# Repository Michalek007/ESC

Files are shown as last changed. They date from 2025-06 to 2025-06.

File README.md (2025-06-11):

# ESC
Electronic speed control for BLDC motors with 6STEP algorithm.

## Hardware
Schematics and PCB project. ESC was based on STSPIN32F0A microcontroller and PSMNR55-40SSH MOSFETs.

## Firmware
Code for STSPIN32F0A in C. Implementation of a 6-step algorithm for controlling motor speed using the Motor SDK. Controlling motor speed with PWM and DShot protocol. UART interface for motor's telemetry.

## ESC Pilot
Python application that communicates with the ESC via UART, enabling motor testing, telemetry collection, and motor speed control.

## Images
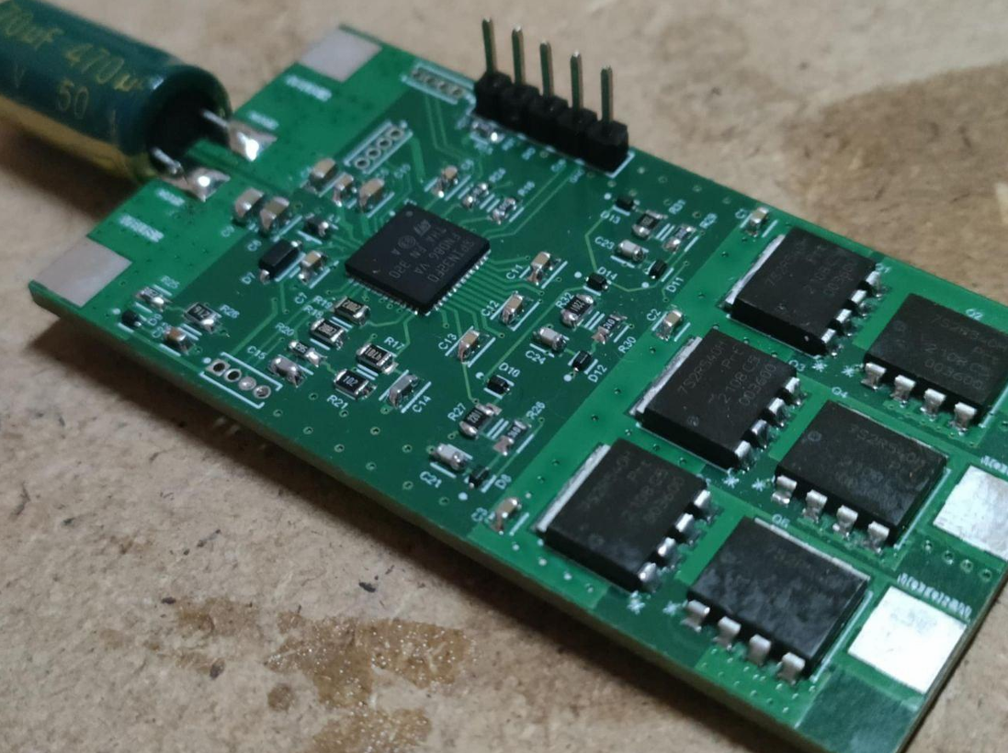
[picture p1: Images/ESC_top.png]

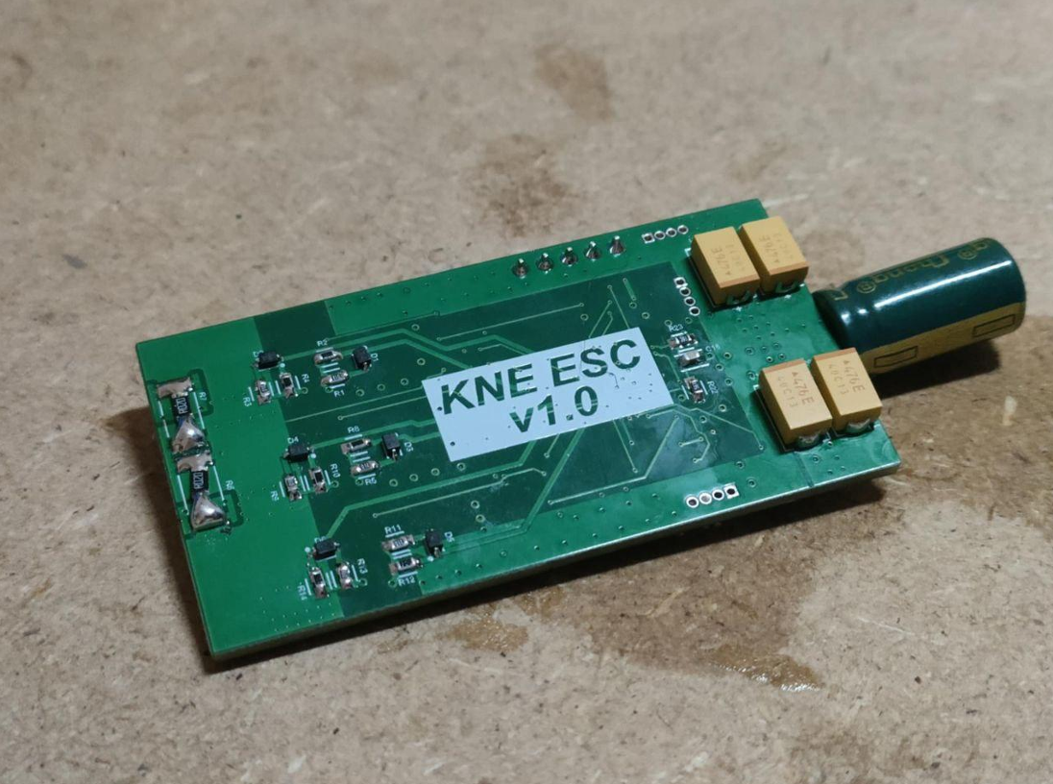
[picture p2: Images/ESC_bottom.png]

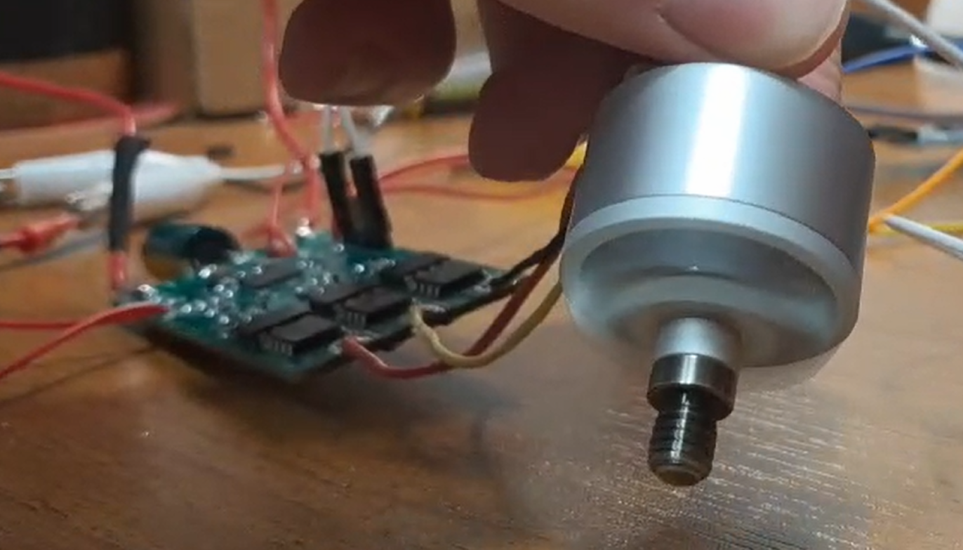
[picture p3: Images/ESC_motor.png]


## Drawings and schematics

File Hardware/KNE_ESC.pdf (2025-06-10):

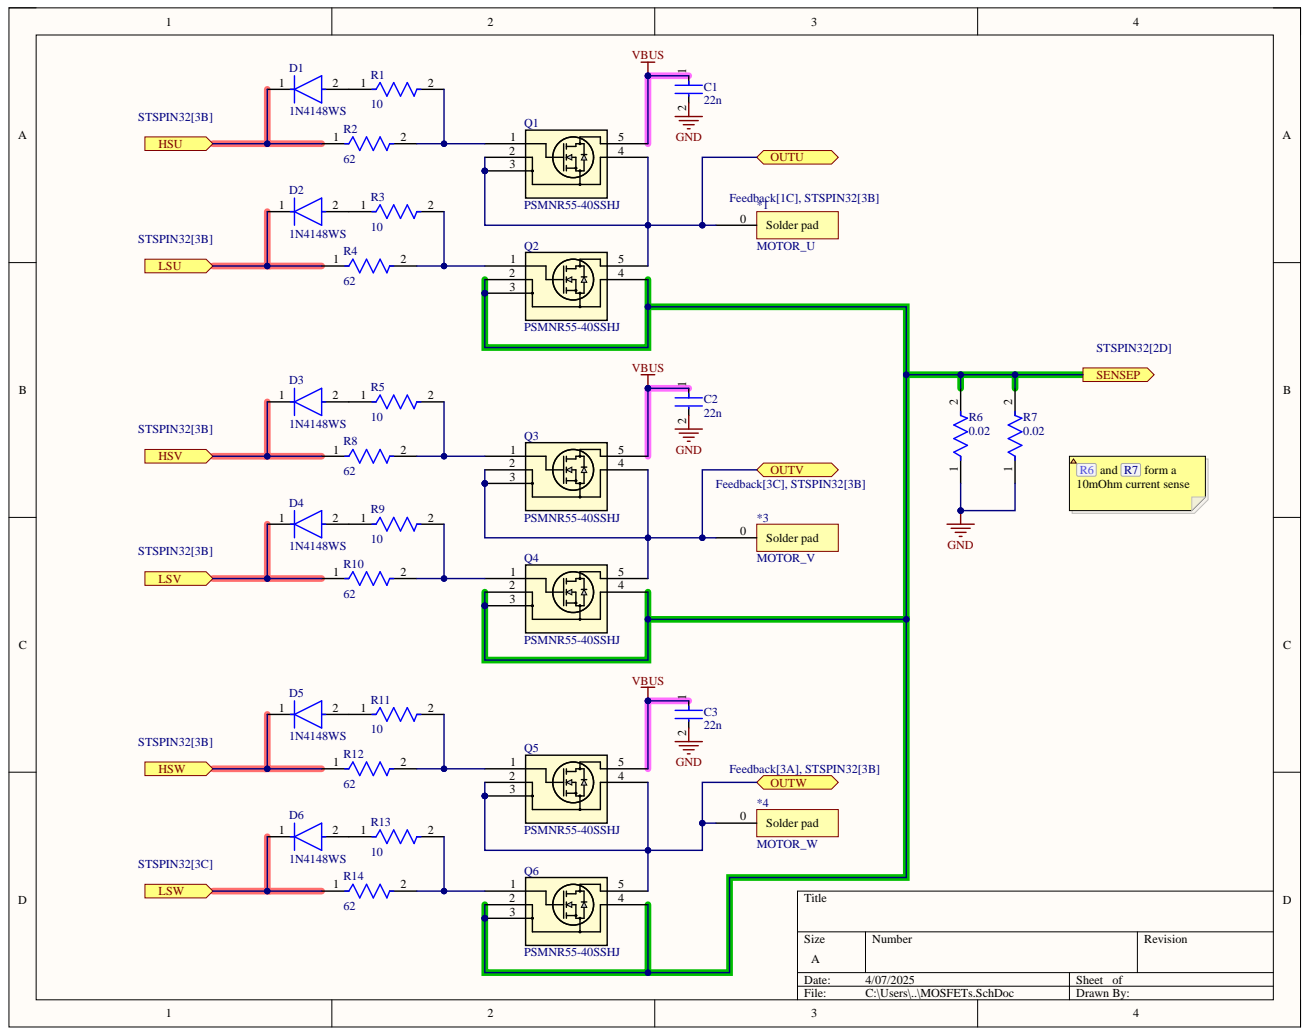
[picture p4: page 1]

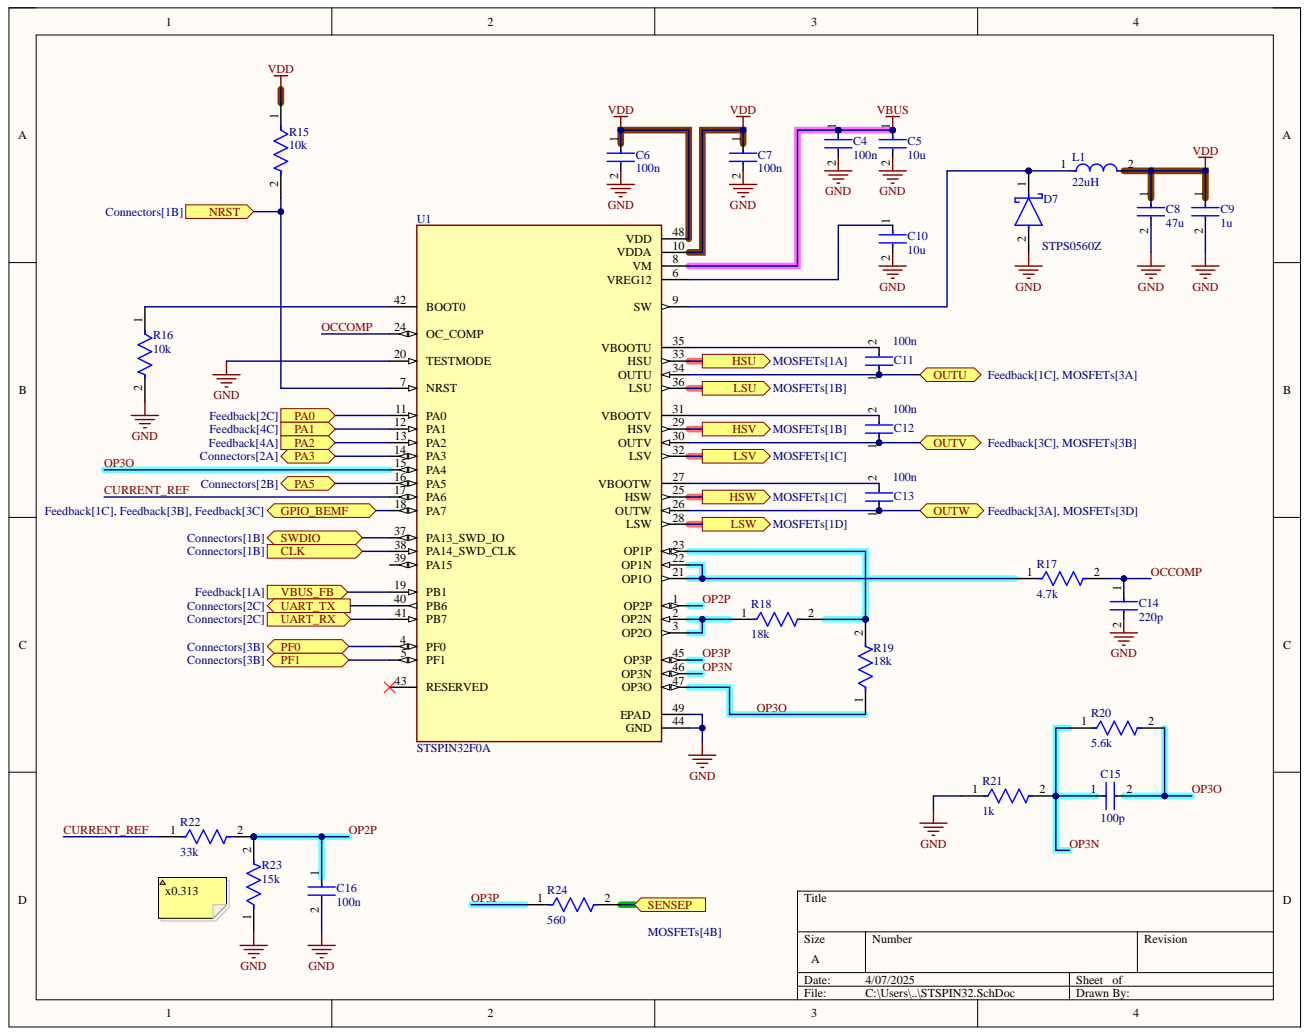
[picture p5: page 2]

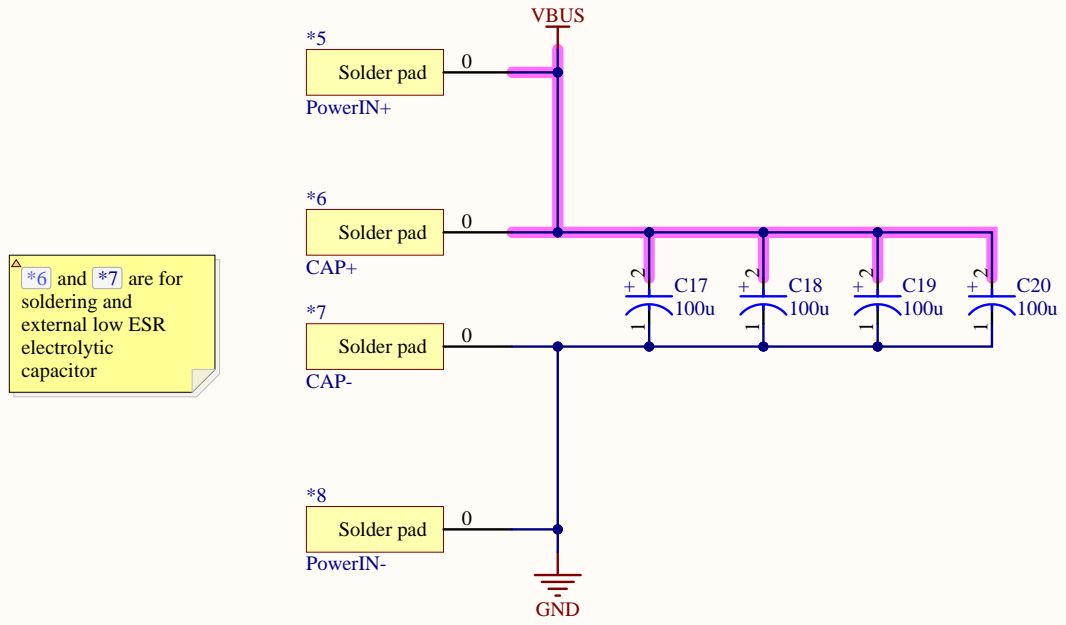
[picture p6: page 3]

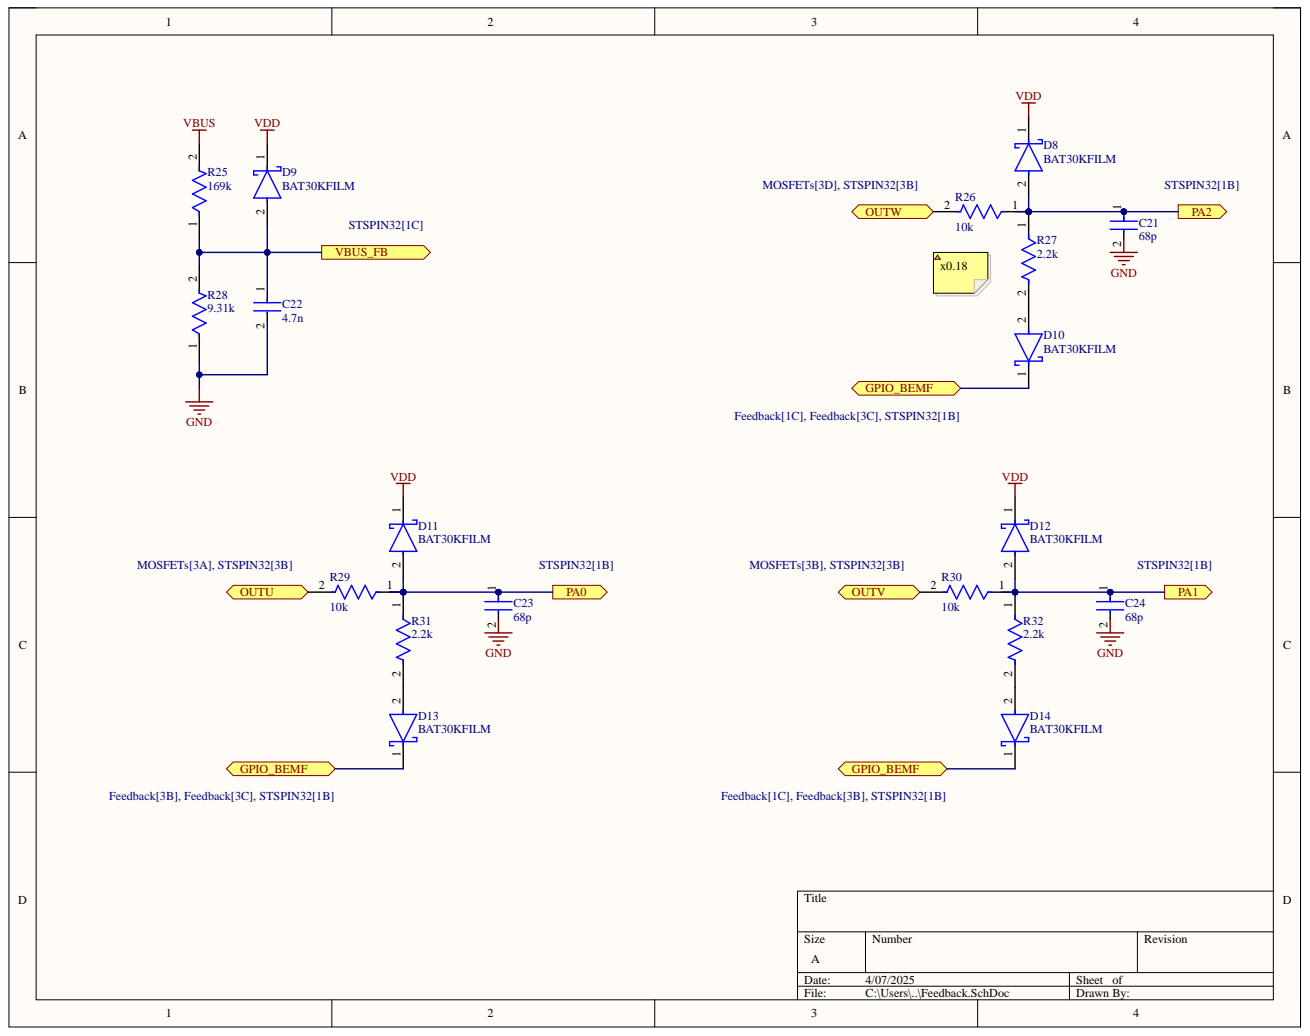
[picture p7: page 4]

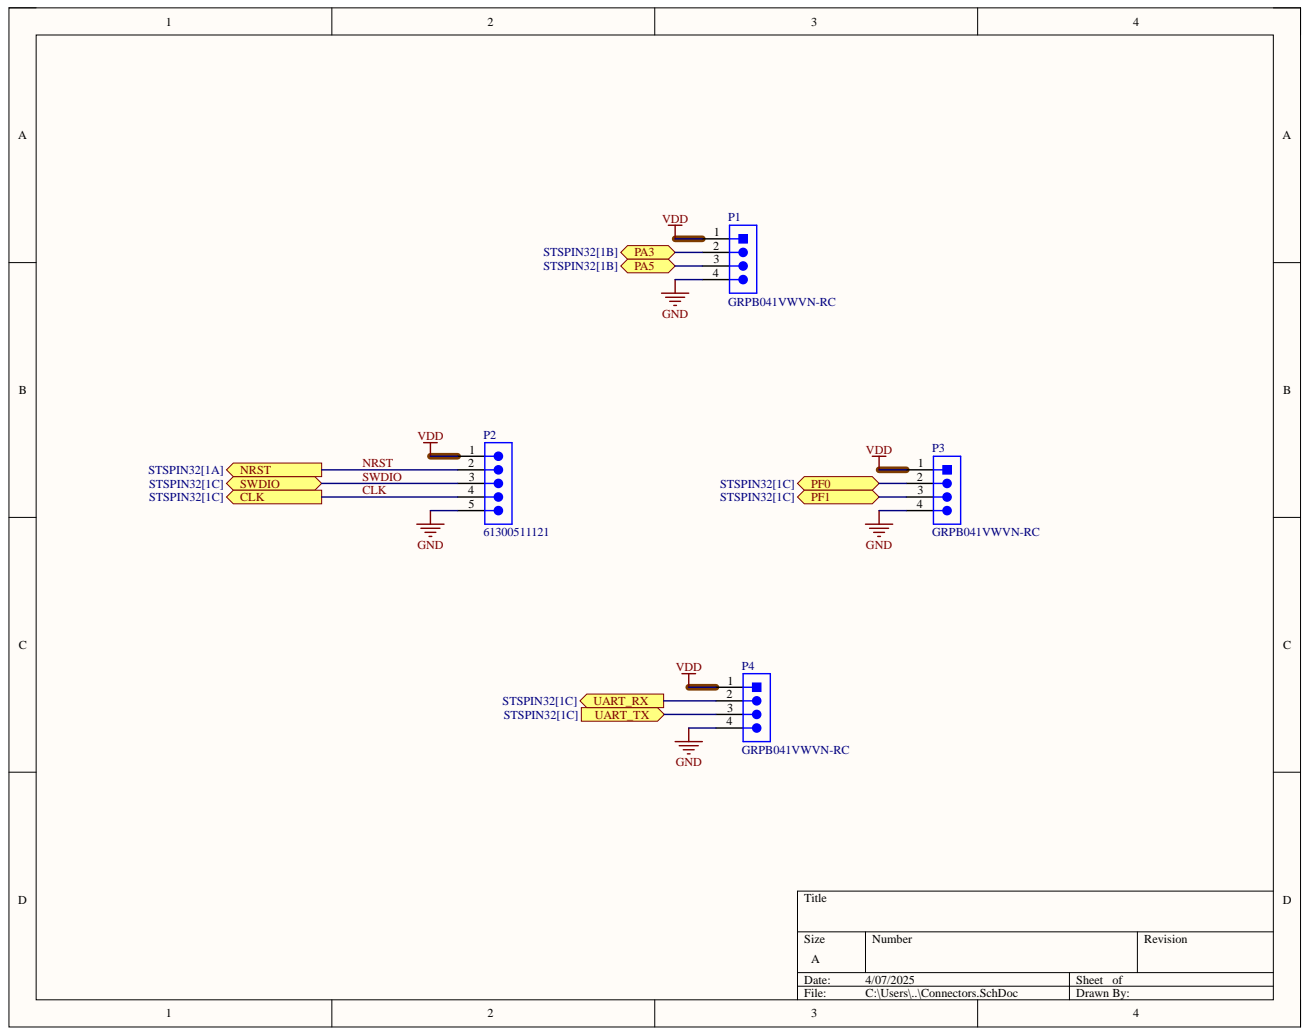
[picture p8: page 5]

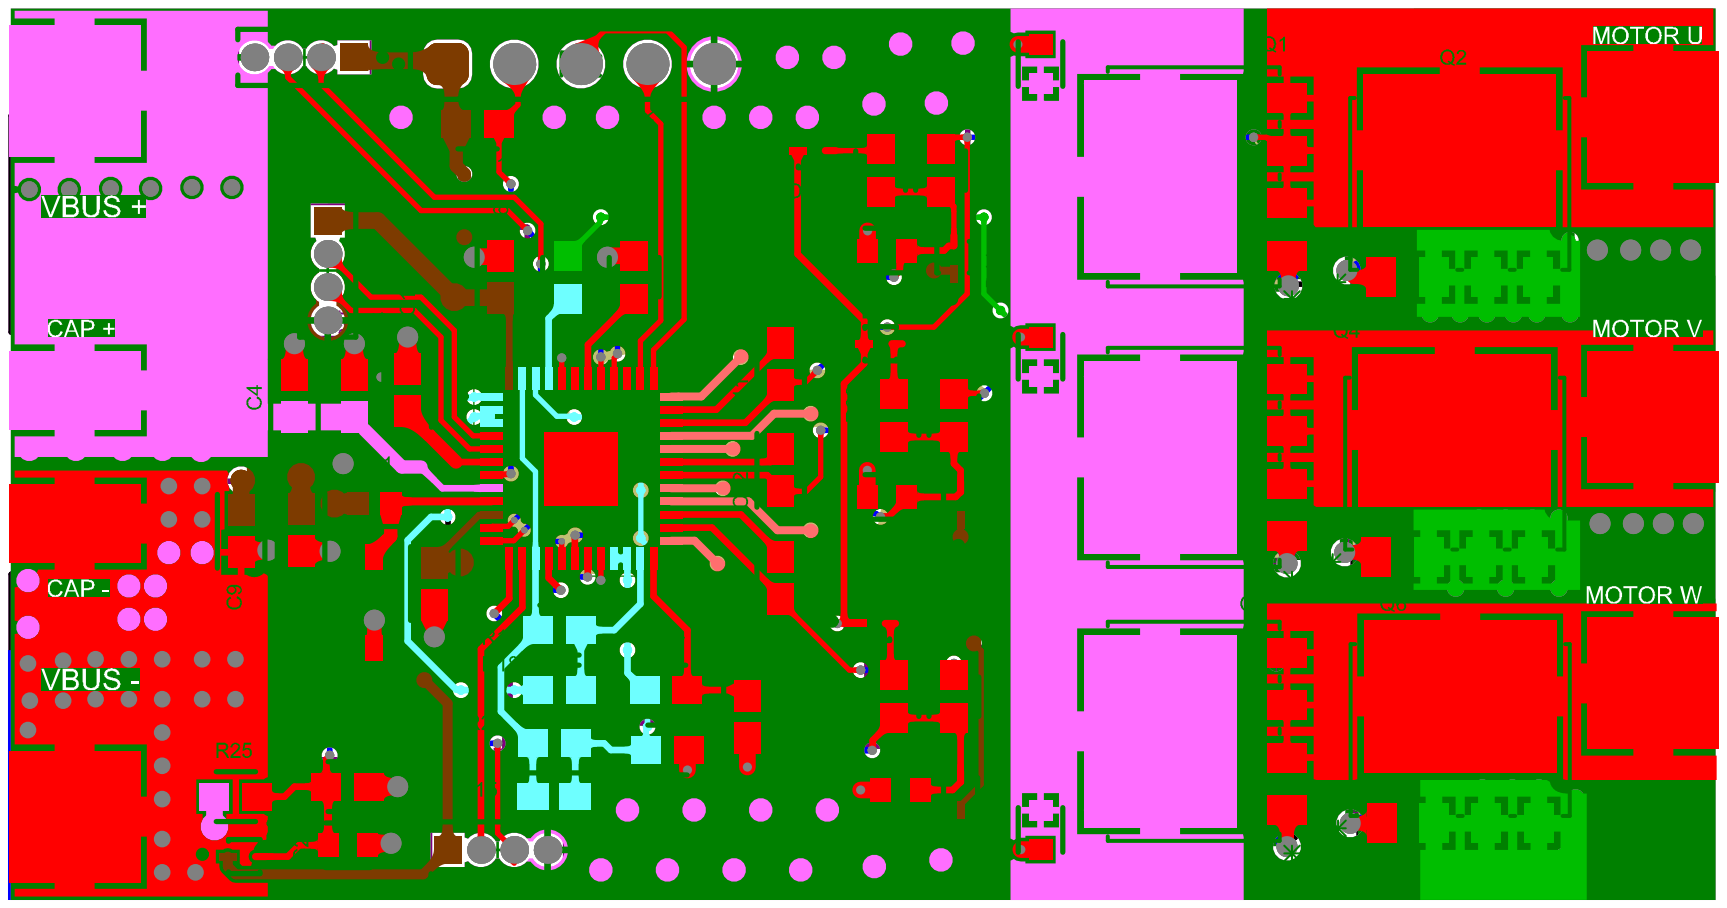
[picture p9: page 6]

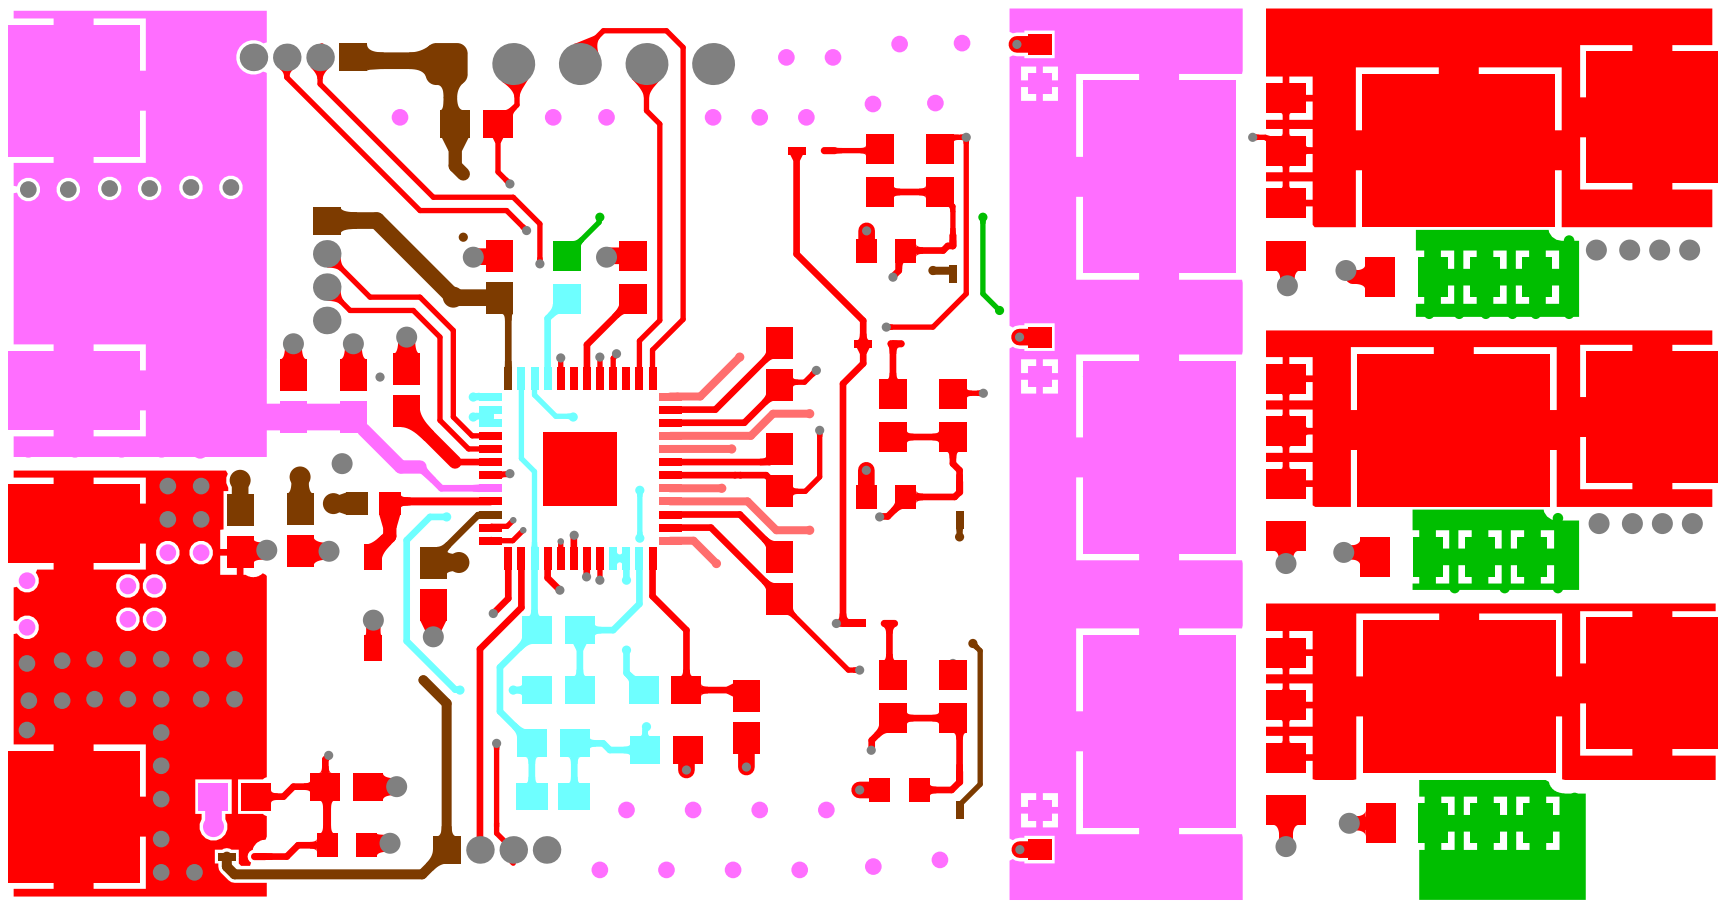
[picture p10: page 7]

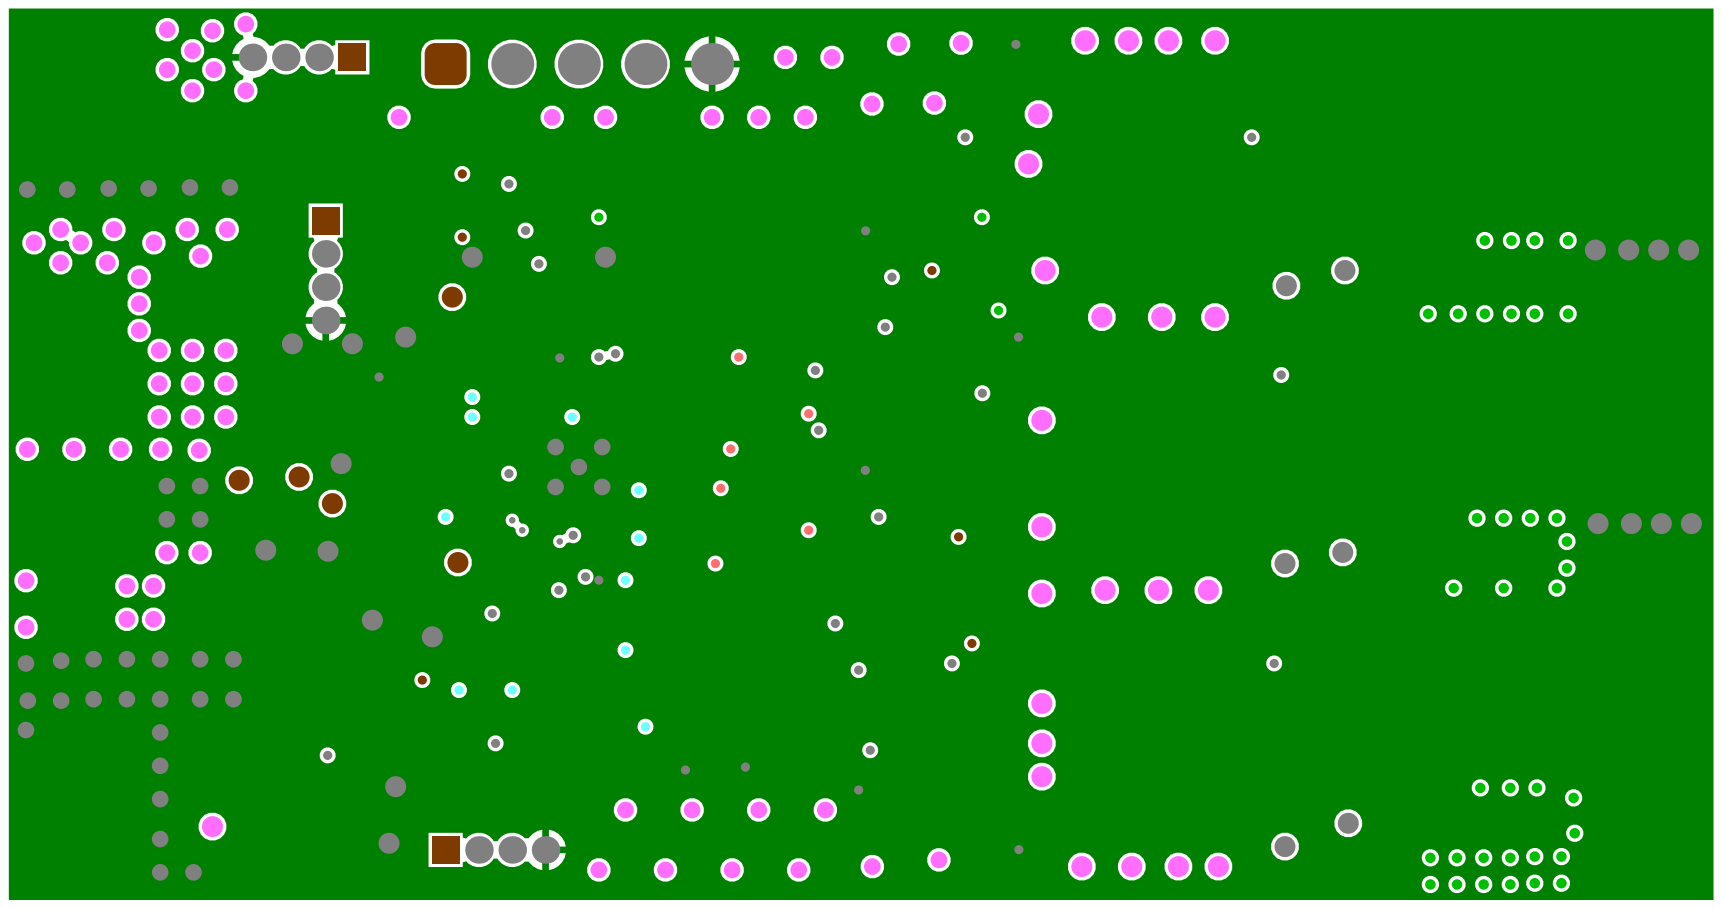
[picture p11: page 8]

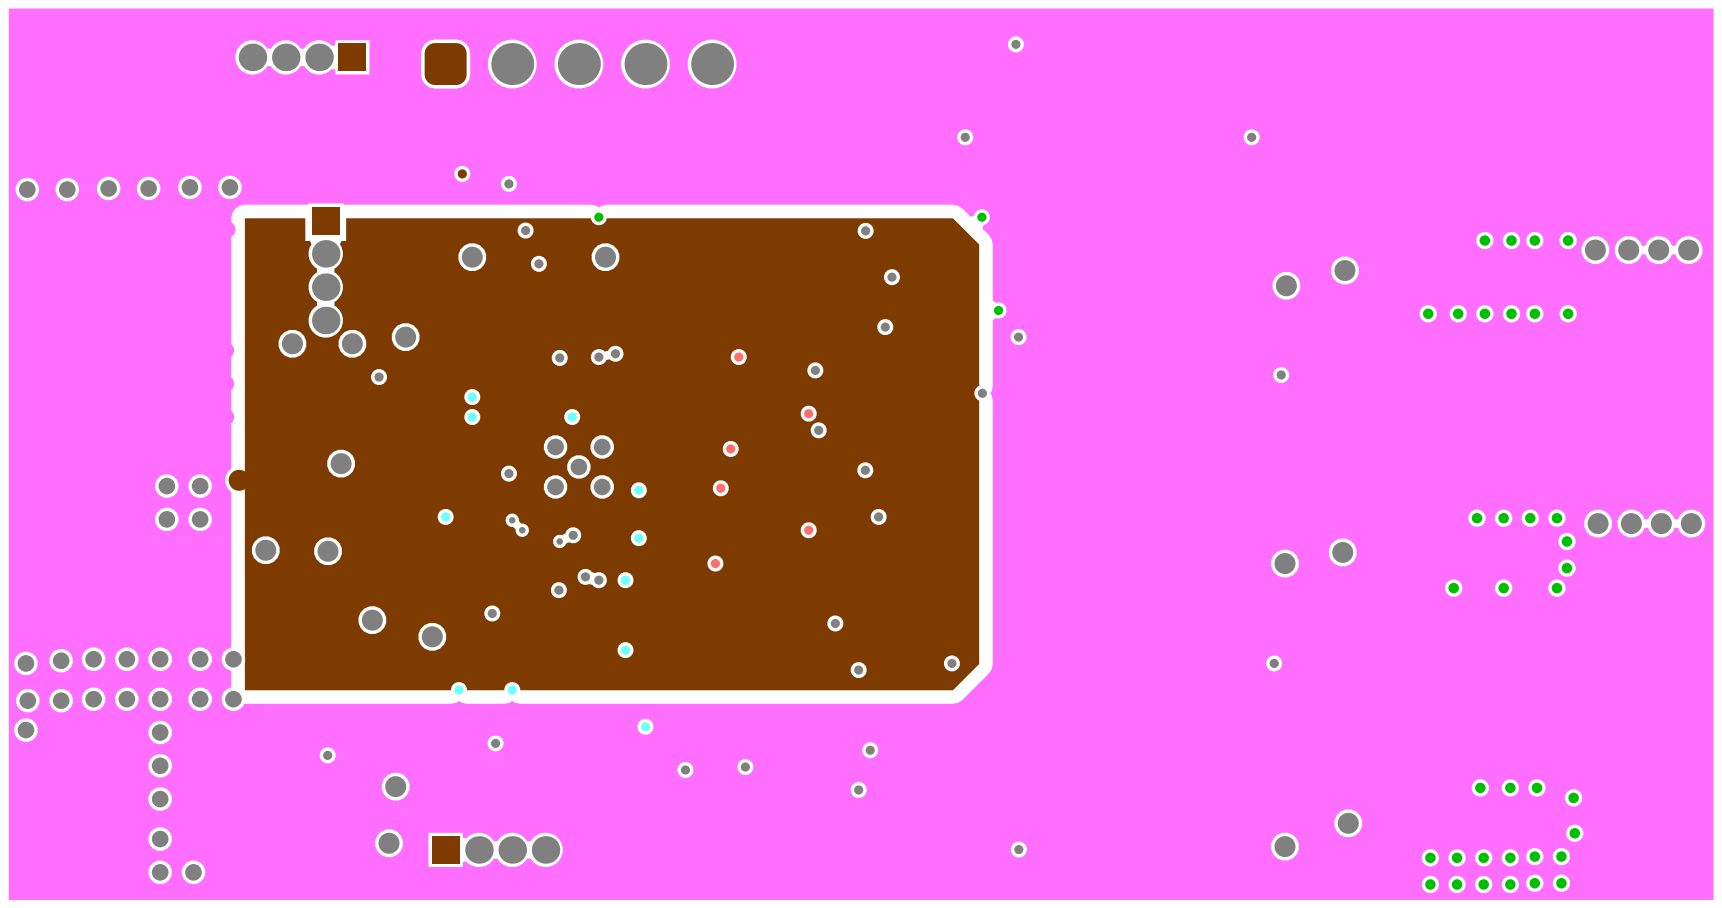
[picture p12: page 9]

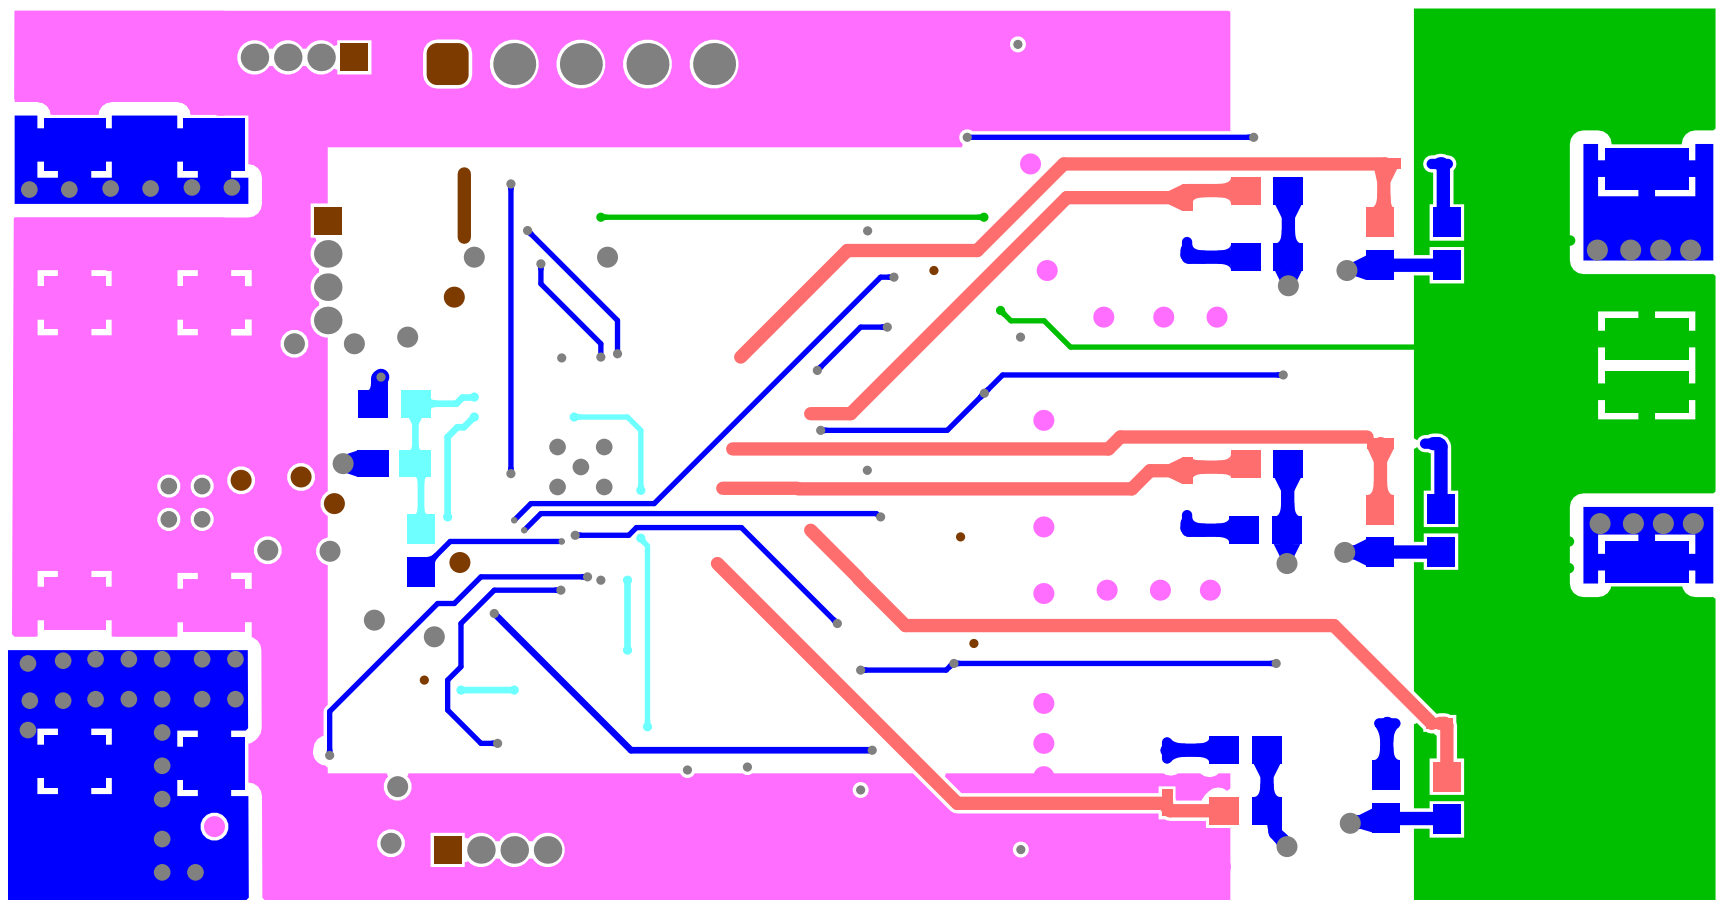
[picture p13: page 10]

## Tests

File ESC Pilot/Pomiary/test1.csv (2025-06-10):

Time | Time | Time | DutyCycle | ReferenceSpeed | AverageSpeed | MotorState
1749584591.8437037 | 2025-06-10 19:43:11.844 | 0.000 | 233 | 4500 | 492 | START
1749584592.9468708 | 2025-06-10 19:43:12.947 | 1.103 | 121 | 3996 | 1494 | RUN
1749584594.0984666 | 2025-06-10 19:43:14.098 | 2.255 | 115 | 3996 | 3468 | RUN
1749584595.1688685 | 2025-06-10 19:43:15.169 | 3.325 | 109 | 3996 | 3720 | RUN
1749584596.2884579 | 2025-06-10 19:43:16.288 | 4.445 | 104 | 4998 | 4698 | RUN
1749584597.3765178 | 2025-06-10 19:43:17.377 | 5.533 | 106 | 4998 | 4938 | RUN
1749584598.4796581 | 2025-06-10 19:43:18.480 | 6.636 | 107 | 4998 | 4980 | RUN
1749584599.599031 | 2025-06-10 19:43:19.599 | 7.755 | 105 | 4998 | 4896 | RUN
1749584600.718403 | 2025-06-10 19:43:20.718 | 8.875 | 109 | 4998 | 5076 | RUN
1749584601.9016843 | 2025-06-10 19:43:21.902 | 10.058 | 102 | 6000 | 5874 | RUN
1749584603.036604 | 2025-06-10 19:43:23.037 | 11.193 | 99 | 6000 | 5796 | RUN
1749584604.1402366 | 2025-06-10 19:43:24.140 | 12.297 | 98 | 6000 | 5748 | RUN
1749584605.3079164 | 2025-06-10 19:43:25.308 | 13.464 | 104 | 6000 | 6006 | RUN
1749584606.4584975 | 2025-06-10 19:43:26.458 | 14.615 | 103 | 6996 | 7056 | RUN
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

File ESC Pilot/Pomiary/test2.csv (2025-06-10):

Time | DutyCycle | ReferenceSpeed | AverageSpeed | MotorState
1749585109.303835 | 801 | 4500 | 0 | IDLE
1749585111.6242926 | 801 | 4500 | 0 | IDLE
1749585113.3018076 | 801 | 4500 | 0 | IDLE
1749585114.9172814 | 801 | 4500 | 0 | IDLE
1749585116.0360553 | 801 | 4500 | 0 | IDLE
1749585117.253012 | 801 | 4500 | 0 | IDLE
1749585118.7549648 | 801 | 4500 | 0 | IDLE
1749585120.2897549 | 801 | 4500 | 0 | IDLE
1749585121.5050356 | 801 | 4500 | 0 | IDLE
1749585122.7847323 | 233 | 4500 | 150 | START
1749585124.4796014 | 114 | 3996 | 1932 | RUN
1749585125.9988434 | 112 | 3996 | 3648 | RUN
1749585127.981447 | 110 | 4998 | 5058 | RUN
1749585129.6124997 | 106 | 4998 | 4938 | RUN
1749585131.2120302 | 109 | 4998 | 5130 | RUN
1749585132.6668863 | 104 | 6000 | 5994 | RUN
1749585134.2183836 | 103 | 6000 | 5994 | RUN
1749585135.769585 | 99 | 6000 | 5808 | RUN
1749585137.2725961 | 99 | 6996 | 6834 | RUN
1749585138.7280366 | 102 | 6996 | 7062 | RUN
1749585140.230938 | 99 | 6996 | 6990 | RUN
1749585141.6537375 | 98 | 6996 | 6894 | RUN
1749585143.0447867 | 90 | 7998 | 7794 | RUN
1749585144.4378734 | 93 | 7998 | 8076 | RUN
1749585145.8917708 | 86 | 7998 | 7980 | RUN
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

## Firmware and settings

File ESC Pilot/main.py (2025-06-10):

import tkinter as tk
from tkinter import ttk
import threading
import time
import struct
import csv
import random
import matplotlib.pyplot as plt
from matplotlib.backends.backend_tkagg import FigureCanvasTkAgg
from mc_api import *


class EscConnectivity:
    def __init__(self):
        self.current_speed = 0
        self.uart = UART()

    def set_speed(self, speed_rpm: int):
        self.uart.send_mc_packet(McPacket.set_speed_rpm(speed_rpm))
        self.current_speed = speed_rpm

    def read_telemetry(self):
        mc_packet = self.uart.send_mc_packet(McPacket.telemetry_request())
        print(mc_packet)
        if not mc_packet:
            return 0, 0, 0, 0, 0
        return mc_packet.duty_cycle, mc_packet.reference_speed, mc_packet.average_speed, mc_packet.motor_state, mc_packet.crc


class MotorGUI:
    def __init__(self, root):
        self.master = root
        self.comm = EscConnectivity()
        self.target_speed = tk.IntVar(value=0)
        self.motor_state_text = tk.StringVar(value="Unknown")
        self.motor_state_label = tk.Label(self.master, textvariable=self.motor_state_text, font=('TkDefaultFont', 12, 'bold'))
        self.motor_state_label.pack()

        self.running = True

        # Logging
        self.telemetry_log = open('telemetry_log.csv', 'w', newline='')
        self.oscillation_log = open('oscillation_log.csv', 'w', newline='')
        self.telemetry_writer = csv.writer(self.telemetry_log)
        self.oscillation_writer = csv.writer(self.oscillation_log)
        self.telemetry_writer.writerow(['Time', 'DutyCycle', 'ReferenceSpeed', 'AverageSpeed', 'MotorState'])
        self.oscillation_writer.writerow(['Time', 'Oscillation (%) (avg)', 'Oscillation (%) (ref)'])

        self.speed_history = []

        self.setup_gui(root)
        threading.Thread(target=self.update_telemetry_loop, daemon=True).start()

    def setup_gui(self, root):
        frame = ttk.Frame(root)
        frame.pack(padx=10, pady=10)

        ttk.Label(frame, text="Target Speed (RPM):").grid(row=0, column=0)
        entry = ttk.Entry(frame, textvariable=self.target_speed)
        entry.grid(row=0, column=1)

        self.slider = ttk.Scale(frame, from_=0, to=10000, orient='horizontal', command=self.slider_changed)
        self.slider.grid(row=1, column=0, columnspan=2, sticky='ew')

        set_btn = ttk.Button(frame, text="Set Speed", command=self.set_speed)
        set_btn.grid(row=2, column=0)

        test_btn = ttk.Button(frame, text="Start Test", command=self.start_test)
        test_btn.grid(row=2, column=1)

        ttk.Label(frame, text="Motor State:").grid(row=3, column=0)
        ttk.Label(frame, textvariable=self.motor_state_text, foreground="blue").grid(row=3, column=1)

        self.fig, self.ax = plt.subplots(3, 1, figsize=(7, 6), tight_layout=True)
        self.canvas = FigureCanvasTkAgg(self.fig, master=root)
        self.canvas.get_tk_widget().pack(fill=tk.BOTH, expand=True)

        self.time_data = []
        self.ref_speed_data = []
        self.avg_speed_data = []
        self.duty_data = []
        self.state_data = []

    def update_motor_state_display(self, state_code):
        state_name = self.get_state_name(state_code)
        self.motor_state_text.set(state_name)

        # Decide color
        if state_name == "RUN":
            color = "green"
        elif state_name in ("ALIGNMENT", "START", "SWITCH_OVER", "CHARGE_BOOT_CAP", "OFFSET_CALIB"):
            color = "orange"
        elif state_name in ("FAULT_NOW", "FAULT_OVER", "STOP", "WAIT_STOP_MOTOR", "ICLWAIT"):
            color = "red"
        elif state_name == "IDLE":
            color = "gray"
        else:
            color = "black"

        self.motor_state_label.config(fg=color)


    def slider_changed(self, val):
        self.target_speed.set(int(float(val)))

    def set_speed(self):
        speed = self.target_speed.get()
        self.comm.set_speed(speed)

    def update_telemetry_loop(self):
        while self.running:
            telemetry = self.comm.read_telemetry()
            if telemetry:
                duty, ref, avg, state, crc = telemetry
                now = time.time()
                self.time_data.append(now)
                self.duty_data.append(duty)
                self.ref_speed_data.append(ref)
                self.avg_speed_data.append(avg)
                self.state_data.append(state)
                self.speed_history.append(avg)
                if len(self.speed_history) > 50:
                    self.speed_history.pop(0)

                self.update_motor_state_display(state)
                
                state_str = self.get_state_name(state) 

                self.telemetry_writer.writerow([now, duty, ref, avg, state_str])
                self.telemetry_log.flush() 
                self.check_oscillations(now, avg, ref)
                self.update_plots()


            time.sleep(0.5)

    def update_plots(self):
        for a in self.ax: a.clear()
        self.ax[0].plot(self.time_data[-100:], self.duty_data[-100:], label='DutyCycle')
        self.ax[1].plot(self.time_data[-100:], self.ref_speed_data[-100:], label='ReferenceSpeed', color='orange')
        self.ax[2].plot(self.time_data[-100:], self.avg_speed_data[-100:], label='AverageSpeed', color='green')
        for a in self.ax:
            a.legend()
            a.grid(True)
        self.canvas.draw()

    STATE_MAP = {
        0: "IDLE",
        2: "ALIGNMENT",
        4: "START",
        6: "RUN",
        8: "STOP",
        10: "FAULT_NOW",
        11: "FAULT_OVER",
        12: "ICLWAIT",
        16: "CHARGE_BOOT_CAP",
        17: "OFFSET_CALIB",
        19: "SWITCH_OVER",
        20: "WAIT_STOP_MOTOR"
    }

    def get_state_name(self, state):
        return self.STATE_MAP.get(state, f"UNKNOWN ({state})")

    def check_oscillations(self, timestamp, avg_speed, ref_speed):
        if len(self.speed_history) < 10:
            return
        mean = sum(self.speed_history) / len(self.speed_history)
        max_dev = max(abs(s - mean) for s in self.speed_history)
        pct_dev_avg = (max_dev / mean) * 100 if mean > 0 else 0
        pct_dev_ref = (max_dev / ref_speed) * 100 if ref_speed > 0 else 0
        self.oscillation_writer.writerow([timestamp, f"{pct_dev_avg:.2f}", f"{pct_dev_ref:.2f}"])

    def start_test(self):
        def test_routine():
            for speed in range(4000, 8001, 1000):
                self.target_speed.set(speed)
                self.slider.set(speed)
                self.set_speed()
                time.sleep(5)
        threading.Thread(target=test_routine, daemon=True).start()

    def on_close(self):
        self.running = False
        self.telemetry_log.close()
        self.oscillation_log.close()


if __name__ == '__main__':
    root = tk.Tk()
    root.title("BLDC ESC Control Panel")
    root.geometry("900x700")
    app = MotorGUI(root)
    root.protocol("WM_DELETE_WINDOW", lambda: (app.on_close(), root.destroy()))
    root.mainloop()

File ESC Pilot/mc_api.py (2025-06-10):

import serial


class McPacket:
    def __init__(self, packet_type: int, data: int, crc: int):
        self.packet_type = packet_type
        self.data = data
        self.crc = crc

    @staticmethod
    def calculate_crc(data: bytes) -> int:
        crc = 0
        for inbyte in data:
            for _ in range(8):
                mix = (crc ^ inbyte) & 0x80
                crc = (crc << 1) & 0xFF  # Ensure it stays within 8 bits
                if mix:
                    crc ^= 0x07
                inbyte = (inbyte << 1) & 0xFF  # Also ensure inbyte stays within 8 bits
        return crc

    @classmethod
    def telemetry_request(cls):
        packet_type = 2
        data = 0
        raw_packet = bytes([packet_type, data, data])
        crc = cls.calculate_crc(raw_packet)
        return cls(packet_type, data, crc)

    @classmethod
    def set_speed_rpm(cls, speed_rpm: int):
        packet_type = 1
        data = speed_rpm
        raw_packet = bytes([packet_type, data & 0xFF, data >> 8])
        crc = cls.calculate_crc(raw_packet)
        return cls(packet_type, data, crc)

    def serialize(self):
        return bytes([self.packet_type, self.data & 0xFF, self.data >> 8, self.crc])


class McTelemetryPacket:
    def __init__(self, duty_cycle: int, reference_speed: int, average_speed: int, motor_state: int, crc: int):
        self.duty_cycle = duty_cycle
        self.reference_speed = reference_speed
        self.average_speed = average_speed
        self.motor_state = motor_state
        self.crc = crc

    @staticmethod
    def calculate_crc(data: bytes) -> int:
        crc = 0
        for inbyte in data:
            for _ in range(8):
                mix = (crc ^ inbyte) & 0x80
                crc = (crc << 1) & 0xFF  # Ensure it stays within 8 bits
                if mix:
                    crc ^= 0x07
                inbyte = (inbyte << 1) & 0xFF  # Also ensure inbyte stays within 8 bits
        return crc

    def serialize(self):
        return bytes([self.duty_cycle & 0xFF, self.duty_cycle >> 8, self.reference_speed & 0xFF, self.reference_speed >> 8, self.average_speed & 0xFF, self.average_speed >> 8, self.motor_state, self.crc])

    def validate(self):
        raw_packet = bytes([self.duty_cycle & 0xFF, self.duty_cycle >> 8, self.reference_speed & 0xFF, self.reference_speed >> 8, self.average_speed & 0xFF, self.average_speed >> 8, self.motor_state])
        return self.crc == self.calculate_crc(raw_packet)

    @classmethod
    def deserialize(cls, data: bytes):
        if len(data) != 8:
            return None
            # raise ValueError("Data must be exactly 8 bytes long.")

        duty_cycle = int.from_bytes(data[0:2], byteorder='little')
        reference_speed = int.from_bytes(data[2:4], byteorder='little')
        average_speed = int.from_bytes(data[4:6], byteorder='little')
        motor_state = data[6]
        received_crc = data[7]

        computed_crc = cls.calculate_crc(data[:7])
        if computed_crc != received_crc:
            raise ValueError(f"CRC mismatch: expected {computed_crc}, got {received_crc}")

        return cls(duty_cycle, reference_speed, average_speed, motor_state, received_crc)

    def __str__(self):
        return (
            f"McTelemetryPacket(\n"
            f"  DutyCycle      : {self.duty_cycle},\n"
            f"  ReferenceSpeed : {self.reference_speed},\n"
            f"  AverageSpeed   : {self.average_speed},\n"
            f"  MotorState     : {self.motor_state},\n"
            f"  CRC            : {self.crc:02X}\n"
            f")"
        )


class UART:
    def __init__(self):
        self.serial = serial.Serial('COM10', 230400, timeout=1)

    def send_mc_packet(self, packet: McPacket):
        self.serial.write(packet.serialize())
        self.serial.flush()

        # read 8 bytes
        if packet.packet_type == 2:
            response = self.serial.read(8)
            return McTelemetryPacket.deserialize(response)

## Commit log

2025-06-10 Added: hardware + tests
    [Connectors.SchDoc, Feedback.SchDoc, KNE_ESC.PrjPcb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]
2025-06-10 Added: ESC Pilot
